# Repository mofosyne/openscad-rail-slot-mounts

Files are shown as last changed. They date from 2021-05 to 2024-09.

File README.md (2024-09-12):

# openscad-rail-slot-mounts
Mount intended for tslot rails (and perhaps vslots later) written in OpenSCAD for easier adjustments

To see what each may look like, you can check the png folder for each design.

This uses makefile to update all the stl of each hooks. And also [docker-openscad](https://github.com/openscad/docker-openscad) as self compiling openscad seems fraught with render errors.

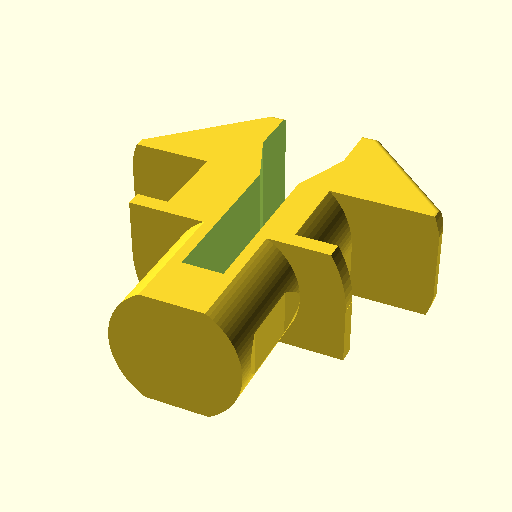
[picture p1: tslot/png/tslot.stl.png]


## Contribution welcomed

Pull request will be accepted. Just don't forget to add your name to this page so we can keep track of everyone.

## Folder Structure

* tslot : These will contain designs that can be immediately used on any tslot rail
    - `tslot.scad` : main template module used by all other parts in this folder
* screw : This contains designs that can be mounted on walls via screws, or tslot or vslot rails via rail nuts or screws.
* vslot : This will contain designs that can be immediately used on any vslot rail (To be done)

## T-Slot Profile Nut

This is a diagram of a typical tslot lock nut



This is a diagram of our tslot soft locking connector



Which would generally be for tslot profiles which might look like

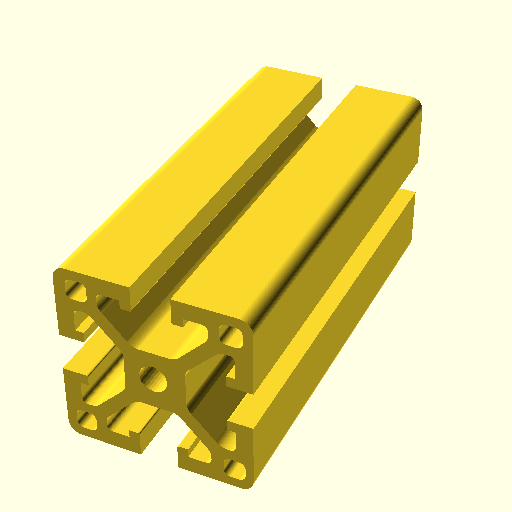
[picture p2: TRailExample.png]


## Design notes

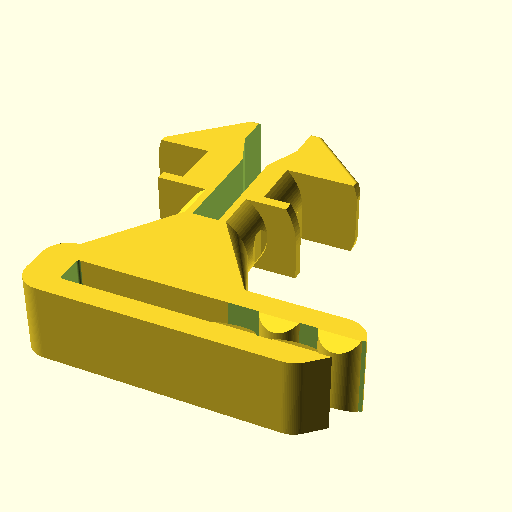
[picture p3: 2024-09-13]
tslot/png/tslot_paper_holder_mini.stl.png

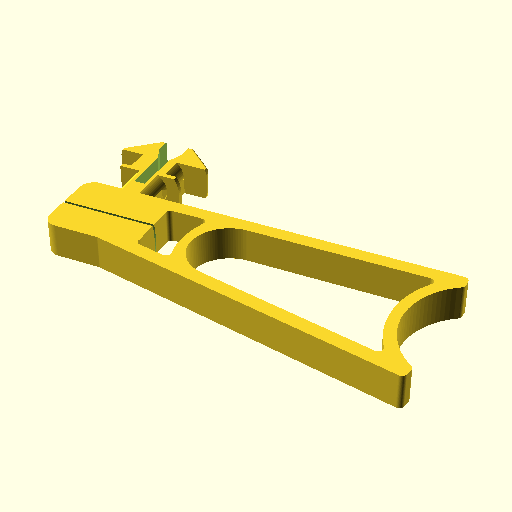
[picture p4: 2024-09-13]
tslot/png/tslot_paper_holder.stl.png

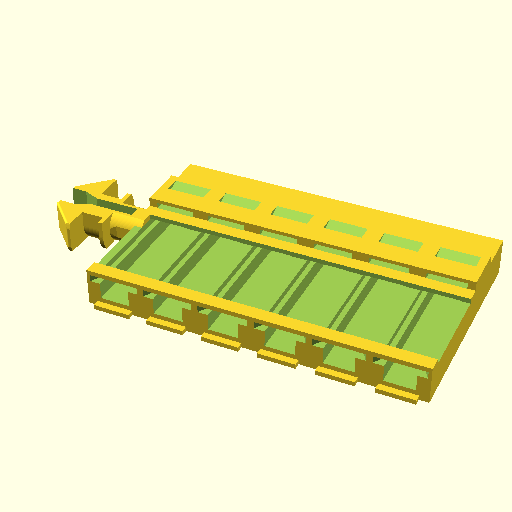
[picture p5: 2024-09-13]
tslot/png/tslot_smd_feeder.stl.png

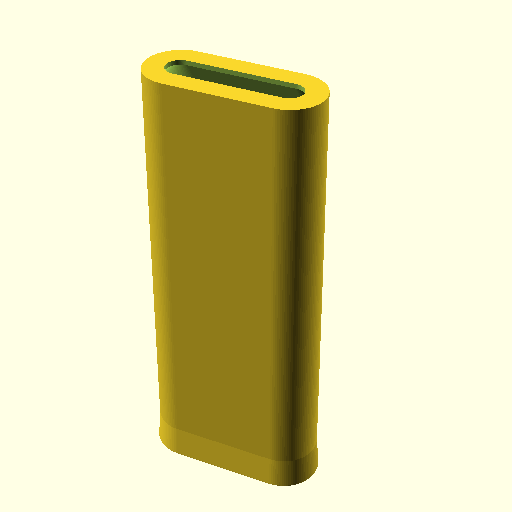
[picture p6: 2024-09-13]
tslot/png/tslot_pen_holder.stl.png

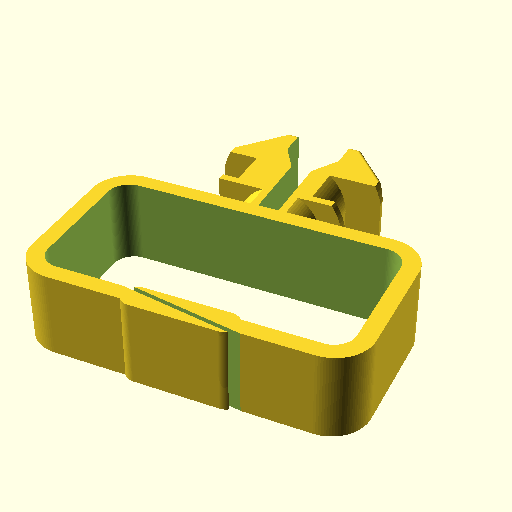
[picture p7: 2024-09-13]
tslot/png/tslot_cable_loop.stl.png

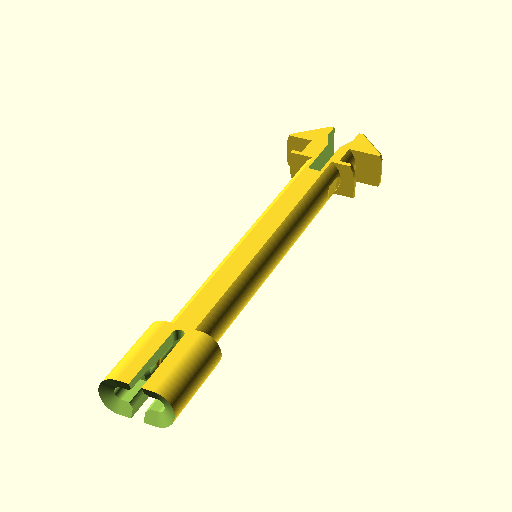
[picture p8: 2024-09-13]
tslot/png/tslot_headphone_mount.stl.png

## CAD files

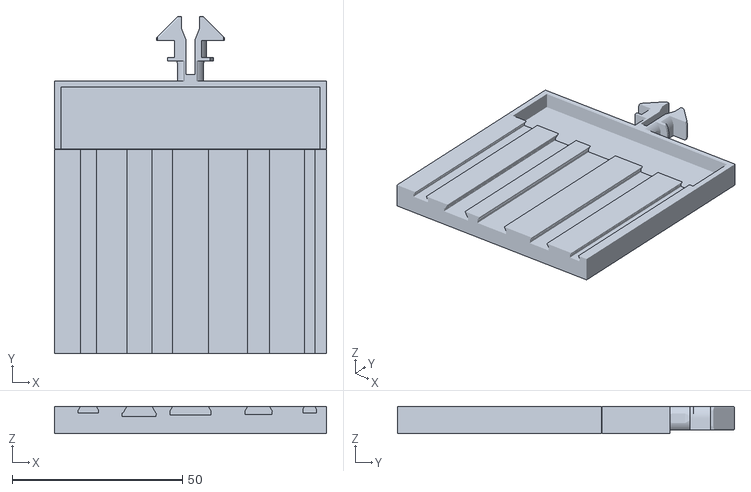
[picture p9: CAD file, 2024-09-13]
tslot/stl/tslot_tape_holderwCatch.stl
80.0 x 99.0 x 8.00

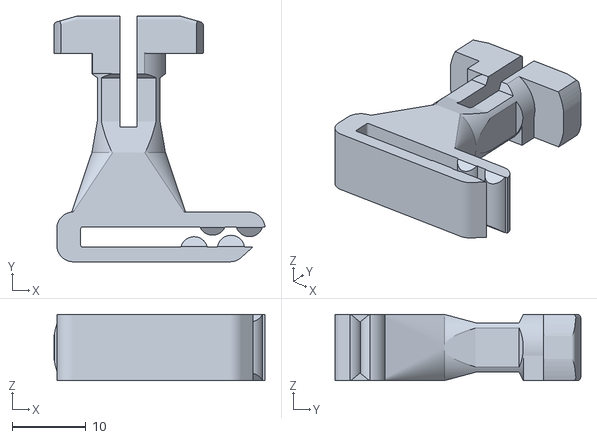
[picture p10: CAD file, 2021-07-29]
tslot/stl_manual/tslot_paper_holder_mini.stl
28.6 x 33.3 x 9.00

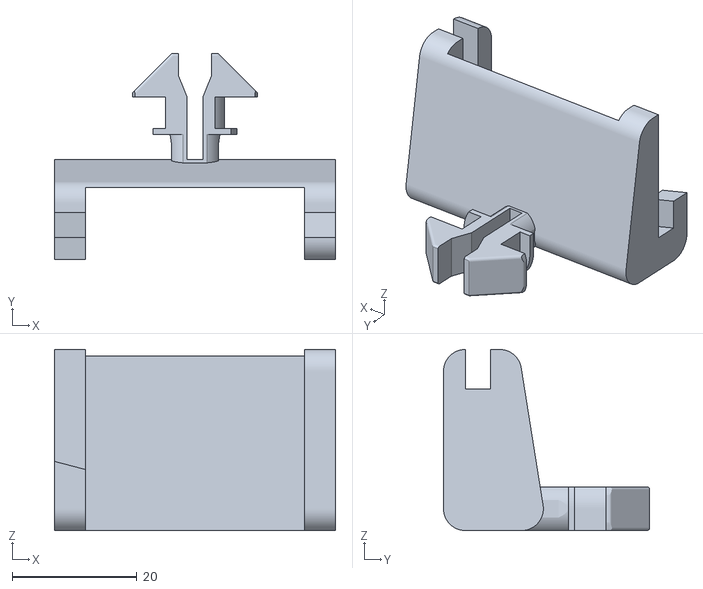
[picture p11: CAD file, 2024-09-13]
tslot/stl/tslot_caliper_holder.stl
45.0 x 33.0 x 29.0

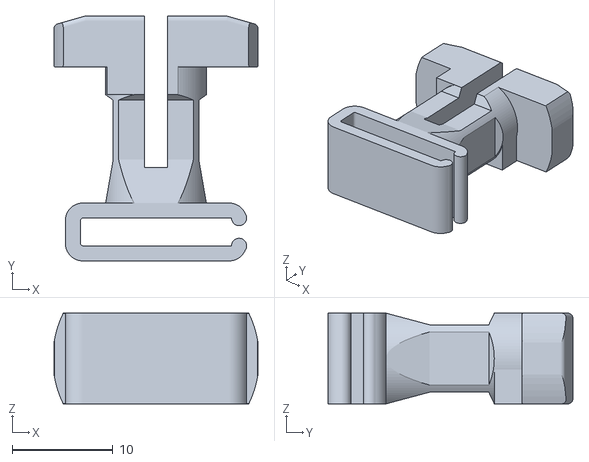
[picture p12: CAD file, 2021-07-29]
tslot/stl_manual/tslot_pcb_slot_mount_15mm_by_2mm_10mmStandoff.stl
20.2 x 24.3 x 9.00

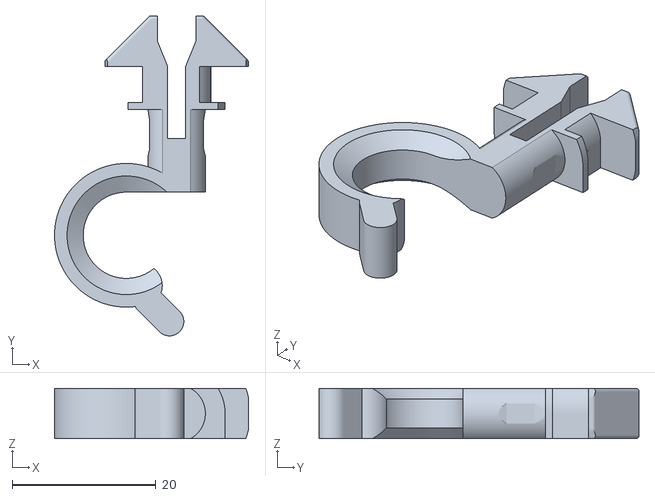
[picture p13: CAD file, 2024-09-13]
tslot/stl/tslot_hook.stl
27.0 x 44.5 x 7.00

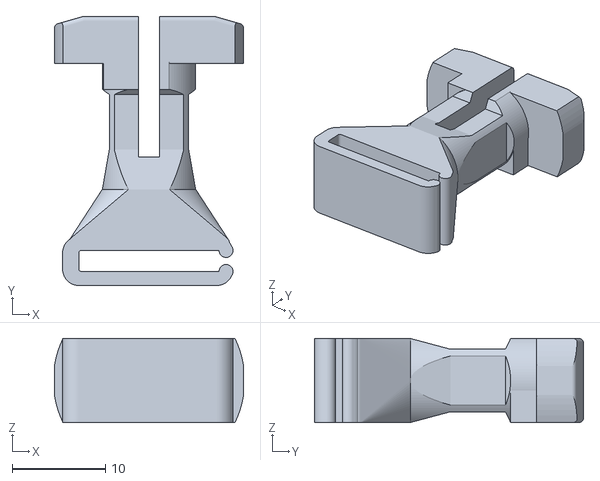
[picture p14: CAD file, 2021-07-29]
tslot/stl_manual/tslot_pcb_slot_mount_15mm_by_2mm_15mmStandoff.stl
20.2 x 28.8 x 9.00

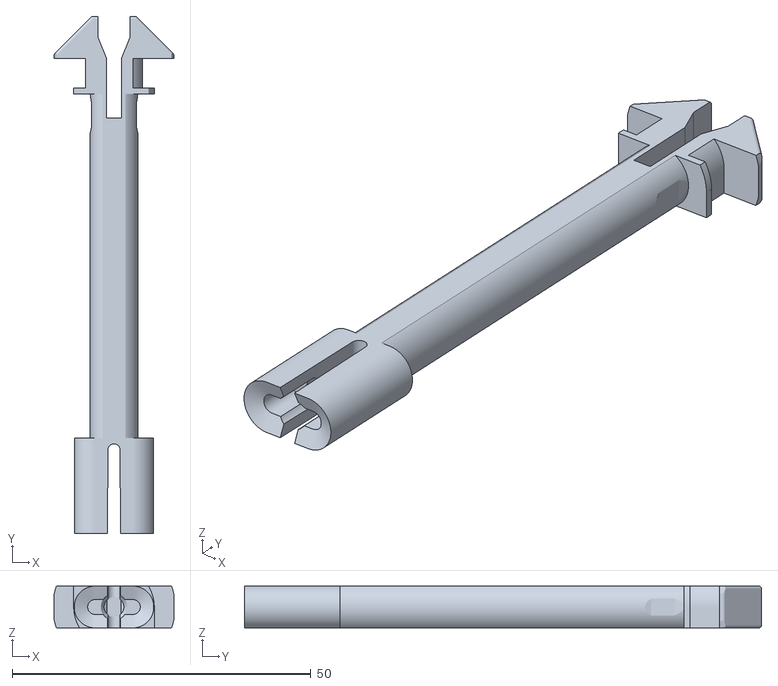
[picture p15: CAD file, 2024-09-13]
tslot/stl/tslot_headphone_mount.stl
20.0 x 86.5 x 7.00

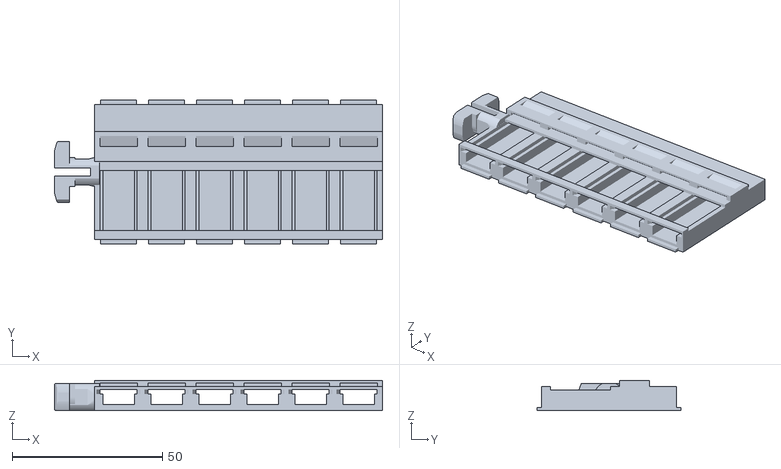
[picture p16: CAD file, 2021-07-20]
tslot/stl_manual/tslot_smd_feeder_12mm.stl
109.3 x 48.0 x 10.0

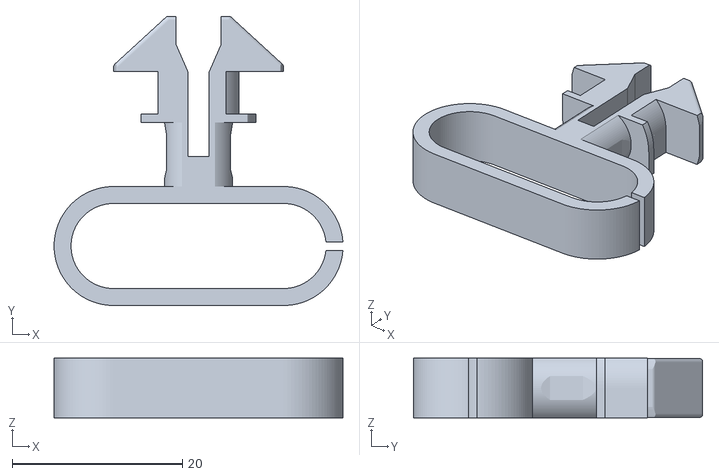
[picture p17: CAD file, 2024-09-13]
tslot/stl/tslot_cable_hook.stl
34.0 x 34.0 x 7.00

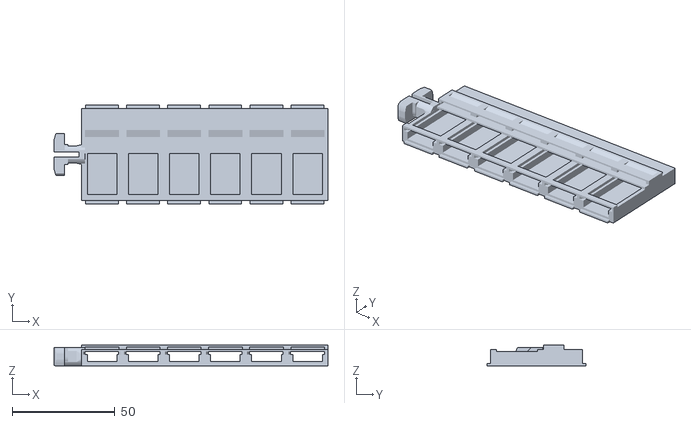
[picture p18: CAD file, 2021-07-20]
tslot/stl_manual/tslot_smd_feeder_16mm.stl
133.3 x 48.0 x 10.0

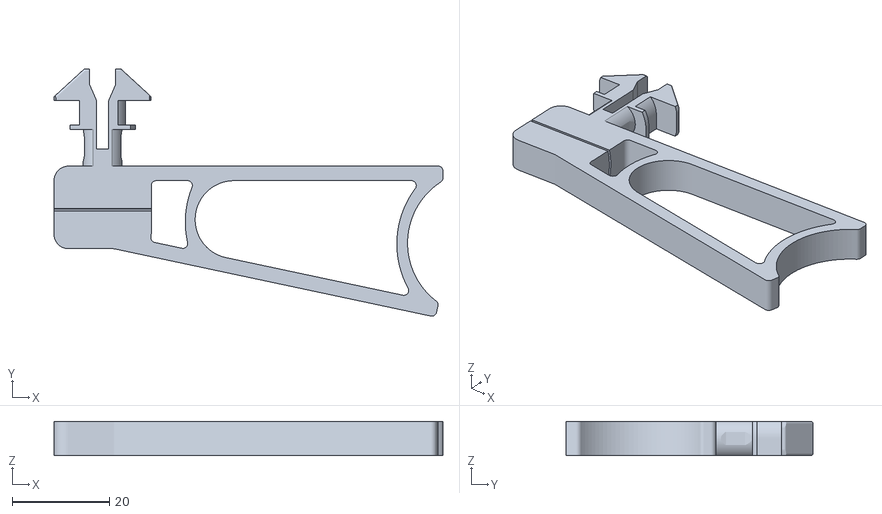
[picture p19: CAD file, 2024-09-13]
tslot/stl/tslot_paper_holder.stl
80.0 x 50.9 x 7.00

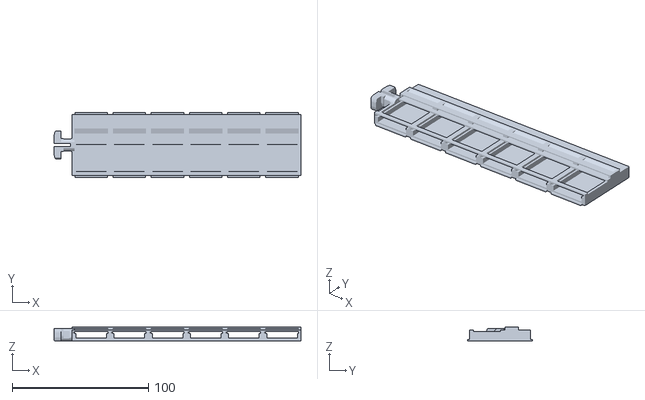
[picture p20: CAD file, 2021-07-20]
tslot/stl_manual/tslot_smd_feeder_24mm.stl
181.3 x 48.0 x 10.0

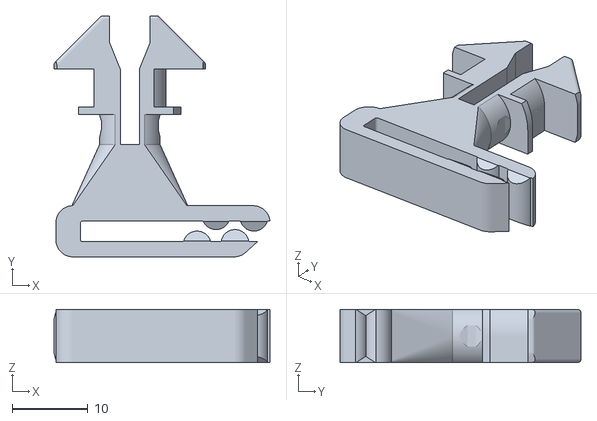
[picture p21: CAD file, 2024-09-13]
tslot/stl/tslot_paper_holder_mini.stl
28.5 x 31.8 x 7.00

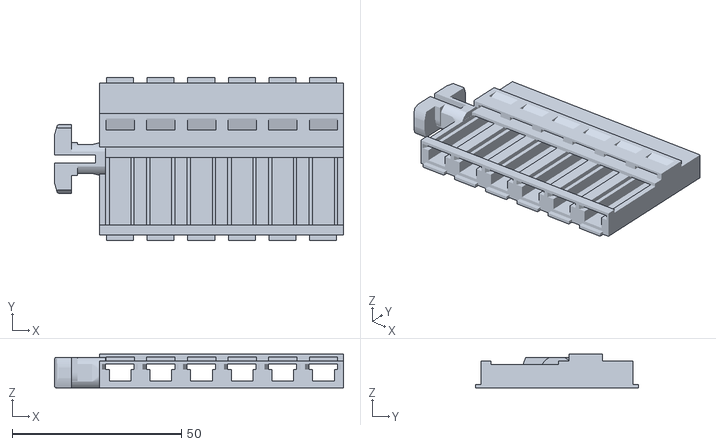
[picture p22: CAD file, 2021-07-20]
tslot/stl_manual/tslot_smd_feeder_8mm.stl
85.3 x 48.0 x 10.0

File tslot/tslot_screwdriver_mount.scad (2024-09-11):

$fn=100;
/*
    Parametric Screwdriver hook For Tslot Mounting
    By Brian Khuu (2020)

    Got a desk with tslot rails, would be nice to screwdriver on it...
*/

use <tslot.scad>

/* [Tslot Spec] */
// CenterDepth
tslot_nut_profile_e = 6.5;
// CenterWidth
tslot_nut_profile_b = 8; // Gap to slot the clip though
// For the wedge... its based on a 4040mm Tslot... so may need to modify polygon() in this script

/* [Screwdriver Spec] */
screwdriver_small_dia = 8;
screwdriver_top_dia = 15;


/* [Tslot Model] */
model_slot_gap = 10;
model_slot_side = 15;


/* [Hook Calc] */
// Hook Diameter
hookdia=screwdriver_small_dia+2;
// Hook Width
standoff=tslot_nut_profile_b-1;
// Hook Thickness
hookthickness=screwdriver_top_dia-hookdia; // This is extra rest for the screwdriver head


translate([0, -1, 0])
union()
{

    translate([0,0,0])
        tslot(tslot_nut_profile_e = tslot_nut_profile_e, tslot_nut_profile_b = tslot_nut_profile_b);

    // Hook
    translate([0, -hookthickness*2, 0])
    union()
    {
        rotate([0,-90,0])
        difference()
        {
            hh = 1;
            xx = hookdia/2+hookthickness;
            hull()
            {
                translate([xx+hh,0,0])
                    cylinder(r=hookdia/2+hookthickness, h=standoff, center=true);
                translate([xx,0,0])
                    cylinder(r=hookdia/2+hookthickness, h=standoff, center=true);

                // Long Flat
                rotate([90,0,0])
                    cylinder(r=tslot_nut_profile_b/2, h=hookdia+hookthickness*2, center=true);
            }

            // Grip Side 1
            hull()
            {
                //Outer
                translate([xx+hh,0,standoff/2+0.5])
                    cylinder(r=(hookdia/2+hookthickness-1), h=0.1, center=true);
                translate([xx   ,0,standoff/2+0.5])
                    cylinder(r=(hookdia/2+hookthickness-1), h=0.1, center=true);
                //Center
                translate([xx+hh,0,0])
                    cylinder(r=hookdia/2, h=1, center=true);
                translate([xx   ,0,0])
                    cylinder(r=hookdia/2, h=1, center=true);
            }

            // Grip Side 2
            hull()
            {
                //Outer
                translate([xx+hh,0,-standoff/2-0.5])
                    cylinder(r=(hookdia/2+hookthickness-1), h=0.1, center=true);
                translate([xx   ,0,-standoff/2-0.5])
                    cylinder(r=(hookdia/2+hookthickness-1), h=0.1, center=true);
                //Center
                translate([xx+hh,0,0])
                    cylinder(r=hookdia/2, h=1, center=true);
                translate([xx   ,0,0])
                    cylinder(r=hookdia/2, h=1, center=true);
            }

            // Degreecut
            translate([hh,0,0])
            hull()
            {
                degreecut = 45;
                // Degreecut
                rotate([0,0,degreecut/2])
                    translate([(hookdia+hookthickness+1),0,0])
                    cube([hookdia+hookthickness+1,1,standoff+2], center=true);
                rotate([0,0,-degreecut/2])
                    translate([(hookdia+hookthickness+1),0,0])
                    cube([hookdia+hookthickness+1,1,standoff+2], center=true);
            }

            // Slide In Cut
            translate([hh,0,0])
            hull()
            {
                translate([(hookdia+hookthickness+10),0,0])
                    cube([1,screwdriver_small_dia+1,standoff+2], center=true);
                translate([((hookdia+hookthickness)/2),0,0])
                    cube([1,screwdriver_small_dia+1,standoff+2], center=true);
            }

            //bottomcut
            translate([-10-standoff/2,-100/2,-100/2])
                cube([10,100,100]);
        }
    }
}

%translate([model_slot_side/2+model_slot_gap/2,0,0]) cube([model_slot_side,0.1,100], center=true);
%translate([-model_slot_side/2-model_slot_gap/2,0,0]) cube([model_slot_side,0.1,100], center=true);

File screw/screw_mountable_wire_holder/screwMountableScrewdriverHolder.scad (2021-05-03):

/*
    Screw mountable screwdriver holder
    Remixed By Brian Khuu (2020 July)
    
    (Based off Screw mountable wire holder but with settings changes)

    Adjusted for pixel lab (2020 July):
    * backplateThickness : Thicker for easier mounting
    * holderLengthA : Reduced to keep screwdriver in place
    * holderLengthB : Reduced to keep screwdriver in place
    * holderAngle : Reduced to keep screwdriver in place
    * countersunkDiameter : Increased a mm to be easier to screw include
    * holderGapSizeDef : 7.5 -> 10.5mm for pixel's mini screwdriver

---------------- Old description ------------
    Screw mountable wire holder
    For use with T-slot V-slots nuts and screws

    Remixed From: Customizable OpenSCAD Wire Holder, Kabelkamm by AndreasG4ris 
    licensed under the Creative Commons - Attribution license. (https://www.thingiverse.com/thing:2823064)
    
    ## For typical usage, just changes these two variables
    drillholeDiameter=8;
    countersunkDiameter=14;
    
*/

backplateThickness=8;
backplateHeight=0; // Set to minimum as we don't need it...
backplateSupportHeight=20;
supportWallThickness=3;
holderThickness=4;
holderLengthA=15;
holderLengthB=10;
holderAngle=40;
cnt=7;
holderGapSizeDef=[10.5,0];
holderGapSizeDefCount=[cnt,1];
holderSizeDef=[11];
holderSizeDefCount=[cnt+1];
fn=40;
drillholeDiameter=8;
countersunkDiameter=15;
countersunkHeight=2;
roundEdge=[true,true,true,true];
backplateHeightTotal=backplateHeight+holderThickness+backplateSupportHeight;
holderGapSize=declareVector(holderGapSizeDef,holderGapSizeDefCount);
holderSize=declareVector(holderSizeDef,holderSizeDefCount);
holderTotalSize=holderSize+holderGapSize;
totalLength=sumVector(holderTotalSize);
totalLengthAccumulate=accumulateVector(holderTotalSize);
count=sumVector(holderSizeDefCount);
assert(count==sumVector(holderGapSizeDefCount));

function sumVector(v) = sumVectorRun(v,0);
function sumVectorRun(v,i) = i<len(v) ? sumVectorRun(v,i+1)+v[i] : 0; 
function accumulateVector(v) = accumulateVectorRun(v,[0]);
function accumulateVectorRun(v,vret) = len(vret)<=len(v) ? accumulateVectorRun(v,concat(vret,[vret[len(vret)-1]+v[len(vret)-1]])) : vret;
function declareVector(v,cnt) = declareVectorRun(v,cnt,[],0,0);
function declareVectorRun(v,cnt,vret,cntNr,vNr) = vNr <= len(v) ? (cntNr < cnt[vNr] ? declareVectorRun(v,cnt,concat(vret,[v[vNr]]),cntNr+1,vNr) : declareVectorRun(v,cnt,vret,0,vNr+1)) : vret;

module quarterZylinder(radius,height,edge) union(){
    intersection(){
        union(){
            cylinder(r=radius,h=height,$fn=fn);
            if(edge)
            sphere(r=radius,$fn=fn);
        }
        translate([0,0,-height])
        cube([radius*2,radius*2,height*4]);
    }
}

module halfZylinder(radius,height){
    translate([height,0,0])
    rotate([0,-90,0])
    difference(){
        cylinder(r=radius,h=height,$fn=fn,center=false);
        translate([0,-2*radius,-height])
        cube([radius*2,4*radius,height*4]);
    }
}

module drillHole(){
    translate([0,-backplateThickness-0.001,0])
    rotate([-90,0,0]){
        translate([0,0,-0.001])
        cylinder(r=drillholeDiameter/2,h=backplateThickness,$fn=fn);
        translate([0,0,backplateThickness-countersunkHeight+0.001])
        cylinder(r1=drillholeDiameter/2,r2=countersunkDiameter/2,h=countersunkHeight+0.002,$fn=fn);
    }

    translate([0,-backplateThickness-0.001,0])
    rotate([-90,0,0]){
        hull()
        {
            translate([0,0,-0.001])
                cylinder(r=drillholeDiameter/2,h=backplateThickness+countersunkHeight,$fn=fn);
            translate([0,100,-0.001])
                cylinder(r=drillholeDiameter/2,h=backplateThickness+countersunkHeight,$fn=fn);
        }
    }
}

module singleHolder(curHolderGapSize,curHolderSize) union(){
    translate([0,-backplateThickness,-backplateSupportHeight])
    cube([curHolderSize+curHolderGapSize,backplateThickness,backplateHeightTotal]);//Backplate
    cube([curHolderSize,holderLengthA,holderThickness]);//Holder A
        
    translate([0,holderLengthA,holderThickness])
    halfZylinder(holderThickness,curHolderSize);
        
    translate([0,holderLengthA,0])
    translate([0,0,holderThickness])
    rotate([holderAngle,0,0])
    translate([0,0,-holderThickness])
    union(){
        hull()
        {
            midlength=curHolderSize*0.8;
            toplength=curHolderSize*0.1;
            translate([0,0,0])
                cube([curHolderSize,3,holderThickness]);
            translate([curHolderSize/2-midlength/2,0,0])
                cube([midlength,holderLengthB*3/4,holderThickness]);
            translate([curHolderSize/2-toplength/2,0,0])
                cube([toplength,holderLengthB,holderThickness]);
            translate([curHolderSize/2-toplength/2,holderLengthB,holderThickness/2])
                rotate([90,0,0])
                    halfZylinder(holderThickness/2,toplength);
        }
    }
    
    translate([-supportWallThickness/2+curHolderSize/2,0,0])
    rotate([0,90,0])
    linear_extrude(height = supportWallThickness)
    polygon(points = [[0,0],[0,holderLengthA],[backplateSupportHeight,0]], paths = [[0,1,2]], convexity=1);

}

module totalHolder(){
    difference()
    {
        union()
        {
            difference(){
                for(i = [0 : count-1]){
                    translate([totalLengthAccumulate[i],0,0])
                    singleHolder(holderGapSize[i],holderSize[i]);
                }
                
                translate([-holderGapSize/2,-backplateThickness,-backplateSupportHeight])
                cube([holderGapSize/2,backplateThickness,backplateHeightTotal]);
                translate([totalLength,-backplateThickness,-backplateSupportHeight])
                cube([holderGapSize/2,backplateThickness,backplateHeightTotal]);
            }
            if(roundEdge[0])
            translate([0,-backplateThickness,-backplateSupportHeight])
            rotate([0,90,0])
            quarterZylinder(backplateThickness,totalLength,roundEdge[3]);

            if(roundEdge[1])
            translate([totalLength,-backplateThickness,-backplateSupportHeight])
            quarterZylinder(backplateThickness,backplateHeightTotal,roundEdge[0]);

            if(roundEdge[2])
            translate([totalLength,-backplateThickness,backplateHeight+holderThickness])
            rotate([0,-90,0])
            quarterZylinder(backplateThickness,totalLength,roundEdge[1]);

            if(roundEdge[3])
            translate([0,-backplateThickness,backplateHeight+holderThickness])
            rotate([0,180,0])
            quarterZylinder(backplateThickness,backplateHeightTotal,roundEdge[2]);
        }
        translate([totalLengthAccumulate[sumVector(holderSizeDefCount)-1]-holderGapSizeDef[0]/2,0,-holderSizeDef[0]+holderThickness])
            drillHole();
        translate([totalLengthAccumulate[sumVector(holderSizeDefCount)/2]-holderGapSizeDef[0]/2,0,-holderSizeDef[0]+holderThickness])
            drillHole();
        translate([totalLengthAccumulate[1]-holderGapSizeDef[0]/2,0,-holderSizeDef[0]+holderThickness])
            drillHole();
    }
}


rotate([90,0,0])
{
    /* Screw Mount Wire Holder */
    totalHolder();
    echo(totalLength);//<350

    /* [Tslot Model] */
    model_slot_gap = 10;
    model_slot_side = 15;

    if (1)
    translate([0,-5,-holderSizeDef[0]+holderThickness])
    rotate([0,90,0])
    union()
    {
        %translate([model_slot_side/2+model_slot_gap/2,0,0]) cube([model_slot_side,0.1,1000], center=true);
        %translate([-model_slot_side/2-model_slot_gap/2,0,0]) cube([model_slot_side,0.1,1000], center=true);
    }
}

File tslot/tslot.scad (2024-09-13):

$fn=100;
/*
    Parametric Headphone Mount For Tslot Mounting
    By Brian Khuu (2020)

    Got a desk with tslot rails, would be nice to screwdriver on it...
*/

/* [Tslot Spec] */
// CenterDepth
//tslot_nut_profile_e = 6.5;
// CenterWidth
//tslot_nut_profile_b = 8; // Gap to slot the clip though
// For the wedge... its based on a 4040mm Tslot... so may need to modify polygon() in this script

// Note: Total height of this object is (tslot_nut_profile_b - cWidthTol), this is done this way to adjust for varying printing tolerance

// 2021-07-28: tslot_nut_profile_e = 7, tslot_nut_profile_b = 10, standoff=7, standoff=5, cWidthTol = 1

module tslot(tslot_nut_profile_e = 7, tslot_nut_profile_b = 8, tslot_nut_profile_g=1, tslot_nut_profile_a=20, tslot_nut_profile_f = 5, standoff=8.5, cWidthTol = 1)
{
    split_grip=1.5;
    split_gap=2;
    split_tol=0.5;
    
    tslot_flexture = standoff;
    flexture_gap_length = 4;

    stabliser_front_length = 1;
    stabliser_front_bump = 2;

    difference()
    {
        union()
        {
            // Tslot Mount Inner
            extraGrip = 0.25;
            translate([0,tslot_flexture+tslot_nut_profile_f,0])
            intersection()
            {
                ss = 0.5; ///< Smoothing
                translate([0,-ss,0])
                minkowski()
                {
                    hull()
                    {
                        negTol = 0.25;
                        posTol = 1.5;
                        translate([0, negTol,0]) cube([(tslot_nut_profile_a)-2*ss, 0.1, tslot_nut_profile_b-cWidthTol-2*ss], center=true);
                        translate([0, tslot_nut_profile_g,0]) cube([(tslot_nut_profile_a)-2*ss, 0.1, tslot_nut_profile_b-cWidthTol-2*ss], center=true);
                        translate([0, tslot_nut_profile_e,0]) cube([tslot_nut_profile_b-2*ss, 0.1, tslot_nut_profile_b-cWidthTol-2*ss], center=true);
                    }
                    sphere(r=ss);
                }
                rotate([-90,0,0])
                    cylinder(r=((tslot_nut_profile_a)/2)+extraGrip, h=tslot_nut_profile_e);
            }

            // Stabliser
            // Note: Added extra 'split_grip' to account for the 'press fit' of the side clips
            translate([0, tslot_flexture+tslot_nut_profile_f/2, 0])
            rotate([-90,0,0])
                intersection()
                {
                    stabTol = 0.25;
                    union()
                    {
                        translate([0,0,0])
                            cylinder(r=(tslot_nut_profile_b-stabTol+split_grip)/2+0.12, h=tslot_nut_profile_f, center=true);
                        translate([tslot_nut_profile_b/4+split_grip, tslot_nut_profile_b/4, 0])
                            cube([(tslot_nut_profile_b-stabTol*2)/2, tslot_nut_profile_b/2, tslot_nut_profile_f], center=true);
                        translate([-tslot_nut_profile_b/4-split_grip, -tslot_nut_profile_b/4, 0])
                            cube([(tslot_nut_profile_b-stabTol*2)/2, tslot_nut_profile_b/2, tslot_nut_profile_f], center=true);
                    }
                    translate([0,0,0])
                        cube([tslot_nut_profile_b+split_grip, tslot_nut_profile_b-cWidthTol, tslot_nut_profile_f], center=true);
                }

            // Stabliser Flats
            translate([0, tslot_flexture-stabliser_front_length/2, 0])
            rotate([-90,0,0])
                intersection()
                {
                    stabTol = 0.25;
                    union()
                    {
                        translate([0,0,0])
                            cylinder(r=(tslot_nut_profile_b-stabTol+split_grip+stabliser_front_bump*2)/2+0.12, h=stabliser_front_length, center=true);
                        translate([tslot_nut_profile_b/4+split_grip+stabliser_front_bump*2, tslot_nut_profile_b/4, 0])
                            cube([(tslot_nut_profile_b-stabTol*2)/2, tslot_nut_profile_b/2, stabliser_front_length], center=true);
                        translate([-tslot_nut_profile_b/4-split_grip-stabliser_front_bump*2, -tslot_nut_profile_b/4, 0])
                            cube([(tslot_nut_profile_b-stabTol*2)/2, tslot_nut_profile_b/2, stabliser_front_length], center=true);
                    }
                    translate([0,0,0])
                        cube([tslot_nut_profile_b+split_grip+stabliser_front_bump*2, tslot_nut_profile_b-cWidthTol, stabliser_front_length], center=true);
                }

            // This will change the stiffness
            slimming=0.5;

            connecting_shaft_height = tslot_nut_profile_b-cWidthTol;
            
            // tslot mount shaft
            rotate([-90,0,0])
                intersection()
                {
                    cheight = tslot_flexture-stabliser_front_length;
                    cylinder(r=tslot_nut_profile_b/2, h=cheight);
                    union()
                    {
                        hull()
                        {
                            translate([0, 0, 0])
                                cube([tslot_nut_profile_b, tslot_nut_profile_b-cWidthTol, 0.01], center=true);
                            translate([0, 0, 1])
                                cube([tslot_nut_profile_b, tslot_nut_profile_b-cWidthTol, 0.01], center=true);
                            translate([0, 0,  2])
                                cube([tslot_nut_profile_b-slimming, connecting_shaft_height, 0.1], center=true);
                        }
                        hull()
                        {
                            translate([0, 0,  2])
                                cube([tslot_nut_profile_b-slimming, connecting_shaft_height, 0.1], center=true);
                            translate([0, 0,  cheight*0.8])
                                cube([tslot_nut_profile_b-slimming, connecting_shaft_height, 0.1], center=true);
                        }
                        hull()
                        {   
                            translate([0, 0,  cheight*0.8])
                                cube([tslot_nut_profile_b-slimming, connecting_shaft_height, 0.1], center=true);
                            translate([0, 0,  cheight])
                                cube([tslot_nut_profile_b, tslot_nut_profile_b-cWidthTol, 0.01], center=true);
                        }
                    }
                }
        }

        // Split
        translate([0, 100/2+tslot_flexture-stabliser_front_length-flexture_gap_length, 0])
            cube([(split_gap+split_tol),100,100], center=true);

        // Hull
        hull()
        {
            translate([0, 100/2+tslot_flexture+tslot_nut_profile_f,0])
                cube([(split_gap+split_tol),100,100], center=true);
            translate([0, 100/2+tslot_flexture+tslot_nut_profile_f+tslot_nut_profile_e/2,0])
                cube([tslot_nut_profile_b*2/3,100,100], center=true);
        }
    }
}


/* [Tslot Model] */
// Using tslot_lock_nut_dia.svg as reference for letter dimentions
model_slot_gap = 10;
model_slot_side = 15;
model_slot_depth = 4;
model_slot_centerdepth = 7;
model_slot_g_side = 1;
model_slot_e_side = 6.5;
model_slot_i_side = model_slot_gap;
//%translate([model_slot_side/2+model_slot_gap/2,0,0]) cube([model_slot_side,model_slot_depth,100], center=true);
//%translate([-model_slot_side/2-model_slot_gap/2,0,0]) cube([model_slot_side,model_slot_depth,100], center=true);

translate([0,4,0])
%difference()
{
    wallDepth=model_slot_depth+5;
    translate([0,model_slot_centerdepth+wallDepth/2,0]) cube([model_slot_side*2+model_slot_gap,wallDepth,100], center=true);

    translate([0,model_slot_centerdepth+model_slot_depth/2,0]) cube([model_slot_gap,model_slot_depth+0.1,100+0.1], center=true);
   
    translate([0,model_slot_centerdepth+model_slot_depth/2+model_slot_g_side/2,0]) cube([20,model_slot_g_side+0.1,100+0.1], center=true);

    hull()
    {
        translate([0,model_slot_centerdepth+model_slot_depth/2+model_slot_g_side,0]) cube([20,0.1,100+0.1], center=true);
        translate([0,model_slot_centerdepth+model_slot_depth/2+(model_slot_g_side+model_slot_e_side),0]) cube([model_slot_i_side,0.1,100+0.1], center=true);
    }
}

//rotate([0,90,0])
tslot();

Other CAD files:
tslot/stl/tslot_pen_holder.stl
tslot/stl/tslot.stl
tslot/stl/tslot_smd_feeder.stl
tslot/stl/tslot_cable_loop.stl
tslot/tslot_cable_hook.scad
TRailExample.scad
screw/screw_mountable_smd_cut_tape_holder/screwCutOfImportedSTL.scad
screw/screw_mountable_smd_cut_tape_holder/screwMountableSMDcutTapeHolder.scad
screw/screw_mountable_smd_cut_tape_holder/stl/screwMountableSMDcutTapeHolder.stl
screw/screw_mountable_wire_holder/screwMountableWireHolder.scad
screw/screw_mountable_wire_holder/stl/screwMountableScrewdriverHolder.stl
screw/screw_mountable_wire_holder/stl/screwMountableWireHolder.stl
tslot/stl/tslot_ethernet_cable_clip.stl
tslot/stl/tslot_screwdriver_mount.stl
tslot/tslot_cable_loop.scad
tslot/tslot_caliper_holder.scad
tslot/tslot_ethernet_cable_clip.scad
tslot/tslot_headphone_mount.scad
tslot/tslot_hook.scad
tslot/tslot_paper_holder.scad
tslot/tslot_paper_holder_mini.scad
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

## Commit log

2021-05-03 scad file with makefile directives added in
    [screwCutOfImportedSTL.scad, screwMountableScrewdriverHolder.scad, screwMountableScrewdriverHolder.stl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]
2021-07-20 smd holder
    [screwCutOfImportedSTL.scad, screwMountableSMDcutTapeHolder.scad, screwMountableSMDcutTapeHolder.stl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]
2021-07-21 disable cut tape ledge
    [screwMountableSMDcutTapeHolder.scad, screwMountableSMDcutTapeHolder.stl]
2021-07-29 added pcb slot mount. Cable loop mount also uses the tslot module now
    [screwMountableScrewdriverHolder.stl, screwMountableWireHolder.stl, tslot.scad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]
2021-07-29 tslot mini paper clip
    [tslot_paper_holder_mini.scad, tslot_paper_holder_mini.stl]
2024-09-08 using docker-openscad as the render backend
    [screwMountableScrewdriverHolder.stl, screwMountableWireHolder.stl, tslot.stl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]
2024-09-09 tslot profile adjusted to account for narrow profiles
    [tslot.scad]
2024-09-09 split grip tol
    [tslot.scad]
2024-09-10 adjust tslot base to fit more profiles
    [screwMountableScrewdriverHolder.stl, screwMountableWireHolder.stl, tslot.scad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]
2024-09-10 adjust for printability
    [screwMountableScrewdriverHolder.stl, screwMountableWireHolder.stl, tslot.stl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]
2024-09-10 Sync cable hook, paper holder and screwdriver mount to use tslot.scad
    also pen cup should be a bit thicker
    [tslot_cable_hook.scad, tslot_paper_holder.scad, tslot_pen_holder.scad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]
2024-09-11 refactor tslot source
    [tslot.scad, tslot_cable_hook.scad, tslot_cable_loop.scad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]
2024-09-11 render and add justfile
    [screwMountableScrewdriverHolder.stl, screwMountableWireHolder.stl, tslot.stl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]
2024-09-12 scad: add alignment bumps
    [TRailExample.scad, tslot.scad]
2024-09-12 refactor tslot and pen holder
    [tslot.scad, tslot_pen_holder.scad]
2024-09-12 pen holder hookthickness_minimum increased from 1mm to 1.5mm for print reliability
    [tslot_pen_holder.scad]
2024-09-13 Added caliper mount and adjust pen cut tolerance
    [screwMountableScrewdriverHolder.stl, screwMountableWireHolder.stl, tslot.scad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]
